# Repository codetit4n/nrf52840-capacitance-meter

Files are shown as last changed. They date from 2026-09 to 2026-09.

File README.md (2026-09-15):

# nrf52840-capacitance-meter

A simple [nRF52840](https://www.nordicsemi.com/Products/nRF52840)-based learning project for measuring capacitor values
using RC timing, SAADC measurements, and a hardware timer.

## RC Circuit

<p align="center">
  nRF52840 capacitance meter circuit
</p>

## How it works

The capacitor is charged and discharged through a known resistor using GPIO P0.27. The capacitor voltage is measured at
the RC junction using P0.04 / AIN2.

For a charging capacitor:

```math
V_C(t) = V_{final}\left(1 - e^{-t/RC}\right)
```

After one time constant, $t = RC$, the capacitor reaches approximately 63.2% of its final voltage:

```math
V_C(RC) \approx 0.632V_{final}
```

The firmware first discharges the capacitor close to 0 V, then starts charging it while sampling the voltage through the
SAADC. A hardware timer measures the elapsed time until the voltage crosses the ~63.2% threshold.

With the resistance known, capacitance is calculated from:

```math
C = \frac{t}{R}
```

The meter has been tested across several capacitor values, with measurements compared against a multimeter.

## Hardware

<p align="center">
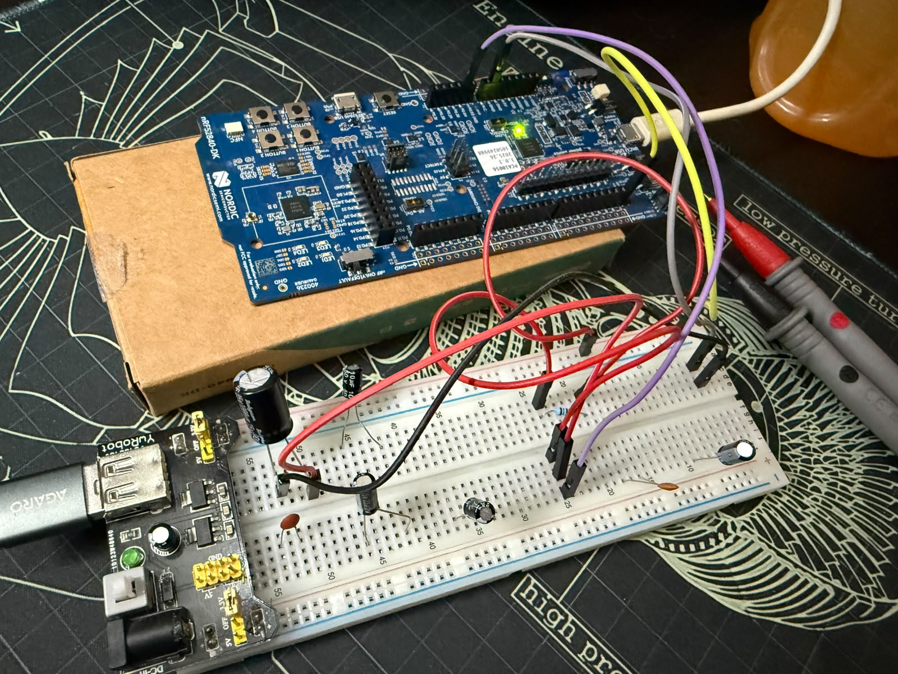
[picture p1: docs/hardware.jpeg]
nRF52840 capacitance meter breadboard setup
  
</p>

<p align="center">
  <em>Breadboard setup used for testing the capacitance meter.</em>
</p>

## Implementation

- Bare-metal firmware without an SDK or RTOS
- GPIO-controlled capacitor charge/discharge
- 12-bit SAADC measurements using EasyDMA
- Hardware timer with 1 µs resolution
- Integer-based voltage and capacitance calculations
- UARTE output for measurement results

### Serial output

UARTE output can be viewed with [Minicom](https://www.man7.org/linux/man-pages/man1/minicom.1.html) at 1M baud:

```shell
minicom -D /dev/ttyACM0 -b 1000000
```

## Measurements

**0.1 µF disc capacitor**

<p align="left">
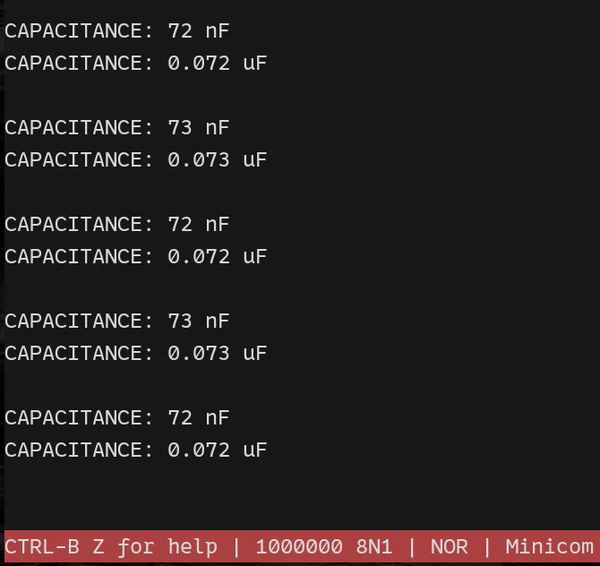
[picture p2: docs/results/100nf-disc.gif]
Firmware measurement of a 0.1 uF disc capacitor
  
</p>

<p align="left">
  <em>Reference (multimeter): 75.7 pF</em>
</p>

**10 µF electrolytic capacitor**

<p align="left">
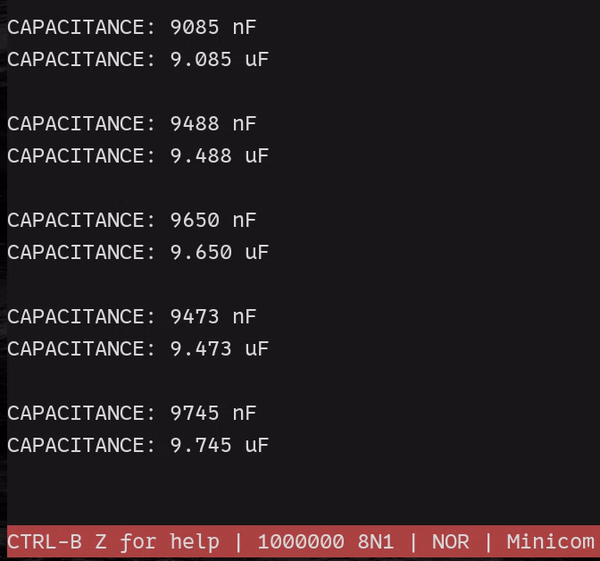
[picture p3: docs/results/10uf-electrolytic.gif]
Firmware measurement of a 10 uF electrolytic capacitor
  
</p>

<p align="left">
  <em>Reference (multimeter): 10.06 µF</em>
</p>

**22 µF electrolytic capacitor**

<p align="left">
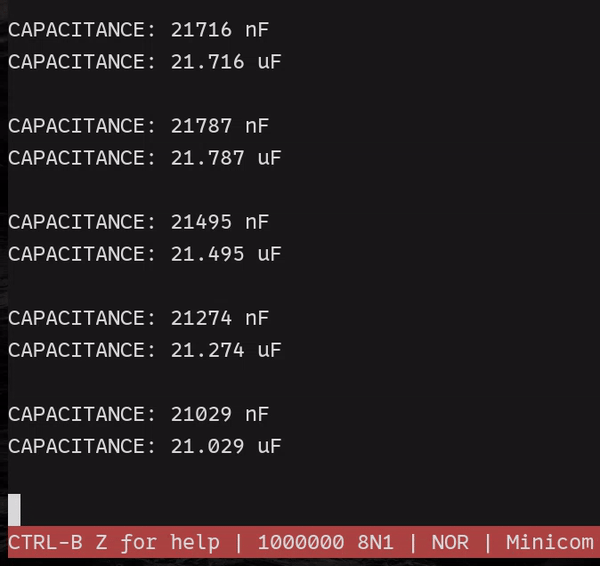
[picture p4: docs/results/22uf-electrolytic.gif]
Firmware measurement of a 22 uF electrolytic capacitor
  
</p>

<p align="left">
  <em>Reference (multimeter): 22.47 µF</em>
</p>

**100 µF electrolytic capacitor**

<p align="left">
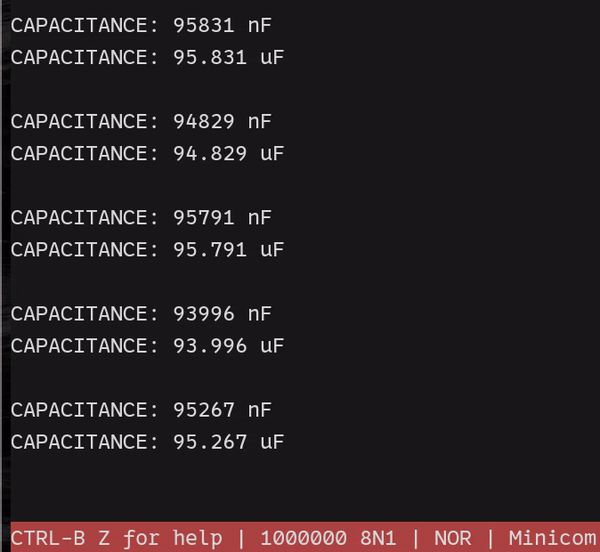
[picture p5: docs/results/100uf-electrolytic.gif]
Firmware measurement of a 100 uF electrolytic capacitor
  
</p>

<p align="left">
  <em>Reference (multimeter): 100.5 µF</em>
</p>

**1000 µF electrolytic capacitor**

<p align="left">
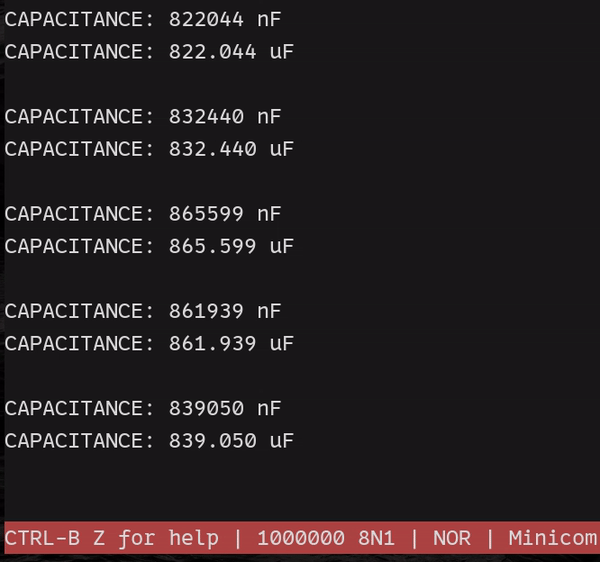
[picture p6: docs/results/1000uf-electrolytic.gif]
Firmware measurement of a 1000 uF electrolytic capacitor
  
</p>

<p align="left">
  <em>Reference (multimeter): 877 µF</em>
</p>

<p align="left">
  <em>Note: Larger capacitors take longer to measure because the charging time increases with the RC time constant, τ = RC.</em>
</p>

## Measurement results

| Capacitor | Multimeter reference | Firmware average |  Error |
| ---: | ---: | ---: | -----: |
| 0.1 µF | 75.7 nF | ~72.4 nF | ~4.36% |
| 10 µF | 10.06 µF | ~9.488 µF | ~5.69% |
| 22 µF | 22.47 µF | ~21.460 µF | ~4.49% |
| 100 µF | 100.5 µF | ~95.143 µF | ~5.33% |
| 1000 µF | 877 µF | ~844.214 µF | ~3.74% |

**Calculation**

```math
\text{Error (\%)} =
\frac{\left|\text{Firmware} - \text{Reference}\right|}
{\text{Reference}}
\times 100
```

## Progress

See [PROGRESS.md](PROGRESS.md) for the implementation checklist.

## Notes

- Some low-level code is reused from my earlier [nRF52840 bare-metal project](https://github.com/codetit4n/nrf52840-baremetal).
- The UARTE logging code is based on [this code](https://github.com/codetit4n/nrf52840-baremetal/blob/main/uarte-tx-only/src/main.c)
  from that project. Read more about it [here](https://loke.sh/blog/nrf52840-web-server/1-nrf52840-baremetal/#uarte-transmit-only-minimal-logger).

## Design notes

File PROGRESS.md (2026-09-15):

# Progress

## Status

**Complete.**

The core capacitance meter implementation is finished, tested across multiple capacitor values, and documented.

## Checklist

- [x] Created bare-metal nRF52840 project
- [x] Added UARTE logging
- [x] Built and tested a basic RC circuit
- [x] Measured the test components with a multimeter
  - Resistor: ~10.03 kΩ
  - Capacitor: ~11.23 µF
- [x] Verified capacitor charge/discharge behavior manually
- [x] Added GPIO-controlled charge/discharge using P0.27
- [x] Fixed common-ground wiring
- [x] Connected the RC measurement point to P0.04 / AIN2
- [x] Configured SAADC channel 0 for AIN2
- [x] Configured SAADC for:
  - single-ended input
  - internal 0.6 V reference
  - 1/6 gain
  - 5 µs acquisition time
  - 12-bit resolution
- [x] Added single-sample SAADC reading using EasyDMA
- [x] Printed raw ADC samples over UARTE
- [x] Verified discharged readings are near 0
- [x] Verified charged readings are stable at ~3430 raw ADC counts
- [x] Converted raw ADC readings to millivolts
- [x] Verified charged voltage is ~3.0 V
- [x] Added voltage-based discharge detection
  - Discharge threshold: 30 mV
- [x] Added voltage-based charge threshold detection
  - Charge threshold: ~1900 mV
  - Based on ~63.2% of the measured final voltage
- [x] Repeatedly sampled the capacitor during charge/discharge
- [x] Verified reliable threshold crossing with SAADC
- [x] Configured a 32-bit hardware timer
- [x] Configured timer for 1 µs resolution
- [x] Started timer when capacitor charging begins
- [x] Captured elapsed time when the charge threshold is reached
- [x] Printed measured charge time over UARTE
- [x] Calculated capacitance from the measured charge time
- [x] Added integer-based nF and µF output
- [x] Fixed arithmetic overflow for larger capacitor values
- [x] Compared calculated capacitance with multimeter readings
- [x] Tested multiple capacitor values
  - ~0.1 µF disc capacitor
  - 10 µF electrolytic capacitor
  - 22 µF electrolytic capacitor
  - 100 µF electrolytic capacitor
  - 1000 µF electrolytic capacitor
- [x] Recorded measurement error and repeatability
- [x] Finished documentation
  - Circuit diagram
  - Hardware setup
  - Measurement demos
  - Measurement comparison
  - README

## Final result

A working bare-metal capacitance meter using RC timing, the nRF52840 SAADC, and a hardware timer.

Tested from approximately 0.1 µF to 1000 µF, with measurements compared against a multimeter.

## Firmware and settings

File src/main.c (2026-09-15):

#include "adc.h"
#include "board.h"
#include "gpio.h"
#include "timer.h"
#include "uarte.h"
#include "utils.h"

int main(void) {
	init_uarte0();
	init_saadc0();
	init_timer0();

	set_pin_output(PIN);

	while (1) {
		/* Discharge capacitor */
		set_pin_low(PIN);

		// uarte_write("CAPACITOR: DISCHARGING\r\n", sizeof("CAPACITOR: DISCHARGING\r\n") -
		// 1);

		uint32_t data = 0;
		do {
			data = saadc_read();
		} while (data > DISCHARGE_THRESHOLD_MV);

		// log_volts(data);

		clear_ctr_and_start_timer();

		/* Charge capacitor */
		set_pin_high(PIN);

		// uarte_write("CAPACITOR: CHARGING\r\n", sizeof("CAPACITOR: CHARGING\r\n") - 1);

		data = 0;
		do {
			data = saadc_read();
		} while (data < CHARGE_THRESHOLD_MV);

		// log_volts(data);

		data = stop_timer_and_read_ctr();

		// log_elapsed_time(data);

		uint32_t nF = ((uint64_t)data * 1000) / 10030;
		log_capacitance_nF(nF);

		uint32_t uF_int = nF / 1000;
		uint32_t uF_frac = nF % 1000;
		uint8_t uF_hundreds = uF_frac / 100;
		uint8_t uF_tens = (uF_frac / 10) % 10;
		uint8_t uF_ones = uF_frac % 10;

		log_capacitance_uF(uF_int, uF_hundreds, uF_tens, uF_ones);

		log_br();
	}
}

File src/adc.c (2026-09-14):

#include "adc.h"
#include "board.h"

static int16_t sample = 0; // SAADC stores sample as 16 bit two's complement value

void init_saadc0(void) {
	ADC_PSELP_REG = ADC_INPUT;
	ADC_RESOLUTION_REG = 2;
	ADC_CONFIG_REG = (0u << 0) |  // RESP   bits 1:0   -> bypass
			 (0u << 4) |  // RESN   bits 5:4   -> bypass
			 (0u << 8) |  // GAIN   bits 10:8  -> 1/6
			 (0u << 12) | // REFSEL bit 12     -> internal 0.6 V
			 (1u << 16) | // TACQ   bits 18:16 -> 5 us
			 (0u << 20) | // MODE   bit 20     -> single-ended
			 (0u << 24);  // BURST  bit 24     -> disabled

	ADC_EVENTS_DONE_REG = 0;

	ADC_ENABLE_REG = 1; // Enable SAADC
}

uint32_t saadc_read(void) {
	ADC_EVENTS_STARTED_REG = 0;
	ADC_EVENTS_DONE_REG = 0;

	ADC_RESULT_PTR_REG = (uint32_t)&sample;
	ADC_RESULT_MAXCNT_REG = 1;

	ADC_TASKS_START_REG = 1;

	while (ADC_EVENTS_STARTED_REG == 0) {
		// wait until SAADC is ready
	}

	ADC_TASKS_SAMPLE_REG = 1;

	while (ADC_EVENTS_DONE_REG == 0) {
		// wait until sample is stored
	}

	if (sample < 0) {
		sample = 0;
	}

	uint32_t milivolts = sample * 3600 / 4095;
	return milivolts;
}

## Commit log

2026-09-08 some resturcturing, progress checklist, RC circuit + testing done
2026-09-09 feat: add SAADC sampling for RC voltage, progress update
2026-09-12 feat: add voltage threshold detection and update docs
2026-09-14 feat: add hardware timer measurement, refactoring
2026-09-15 docs: finalize project documentation and results, small rearrangements
    [architecture.kicad_sch]
